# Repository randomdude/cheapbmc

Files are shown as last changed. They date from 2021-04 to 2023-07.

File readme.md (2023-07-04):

= About = 

This is a very simple tool to control a PC's power state. It offers functions to 'press' the power button (controlled via a relay), the 'reset' button, and to observe the current power state of the PC.

It connects to the PC's ATX power-supply header, and uses an ESP8266 to expose a web interface via SSL. The web interface uses mutual SSL (ie, the client authenticates with a certificate and the server authenticates with a certificate).

= Building =

Refer to the Jenkinsfile, or:

```
git clone https://github.com/Microsoft/vcpkg.git
cd vcpkg
bootstrap-vcpkg.bat
vcpkg integrate install
vcpkg install curl[tool] curl[openssl]
```

You'll need to generate keys first - cd to keys/ and run `generate.sh`.

= Use = 

There's no real commandline tool yet (TODO!) but you can test with cURL.

```
# curl --cert access.crt --key access.key --cacert ca.crt https://192.168.90.23 
<html><head></head><a href="doPower">Power button control</a></br><a href="doReset">Reset button control</a></br><a href="getTargetStatus">Get target power LED state</a></br></html>
# curl --cert access.crt --key access.key --cacert ca.crt https://192.168.90.23/getTargetStatus 
OFF
aliz@nuc:/foo# curl -X POST --cert access.crt --key access.key --cacert ca.crt https://192.168.90.23/doPower?thingToDo=short
```

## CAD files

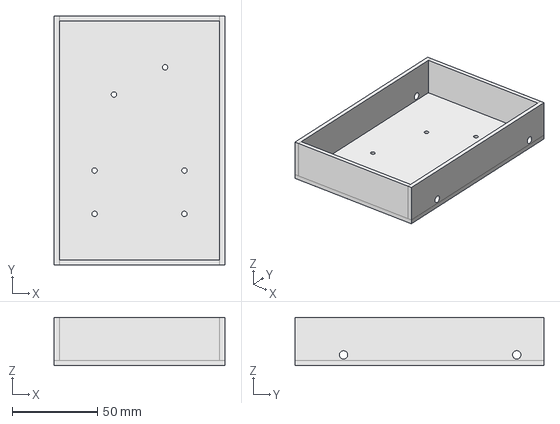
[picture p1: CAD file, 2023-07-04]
enclosure/3_5_inchDiskSized.FCStd
100.2 x 146.1 x 28.4 mm

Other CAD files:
enclosure/globals.FCStd

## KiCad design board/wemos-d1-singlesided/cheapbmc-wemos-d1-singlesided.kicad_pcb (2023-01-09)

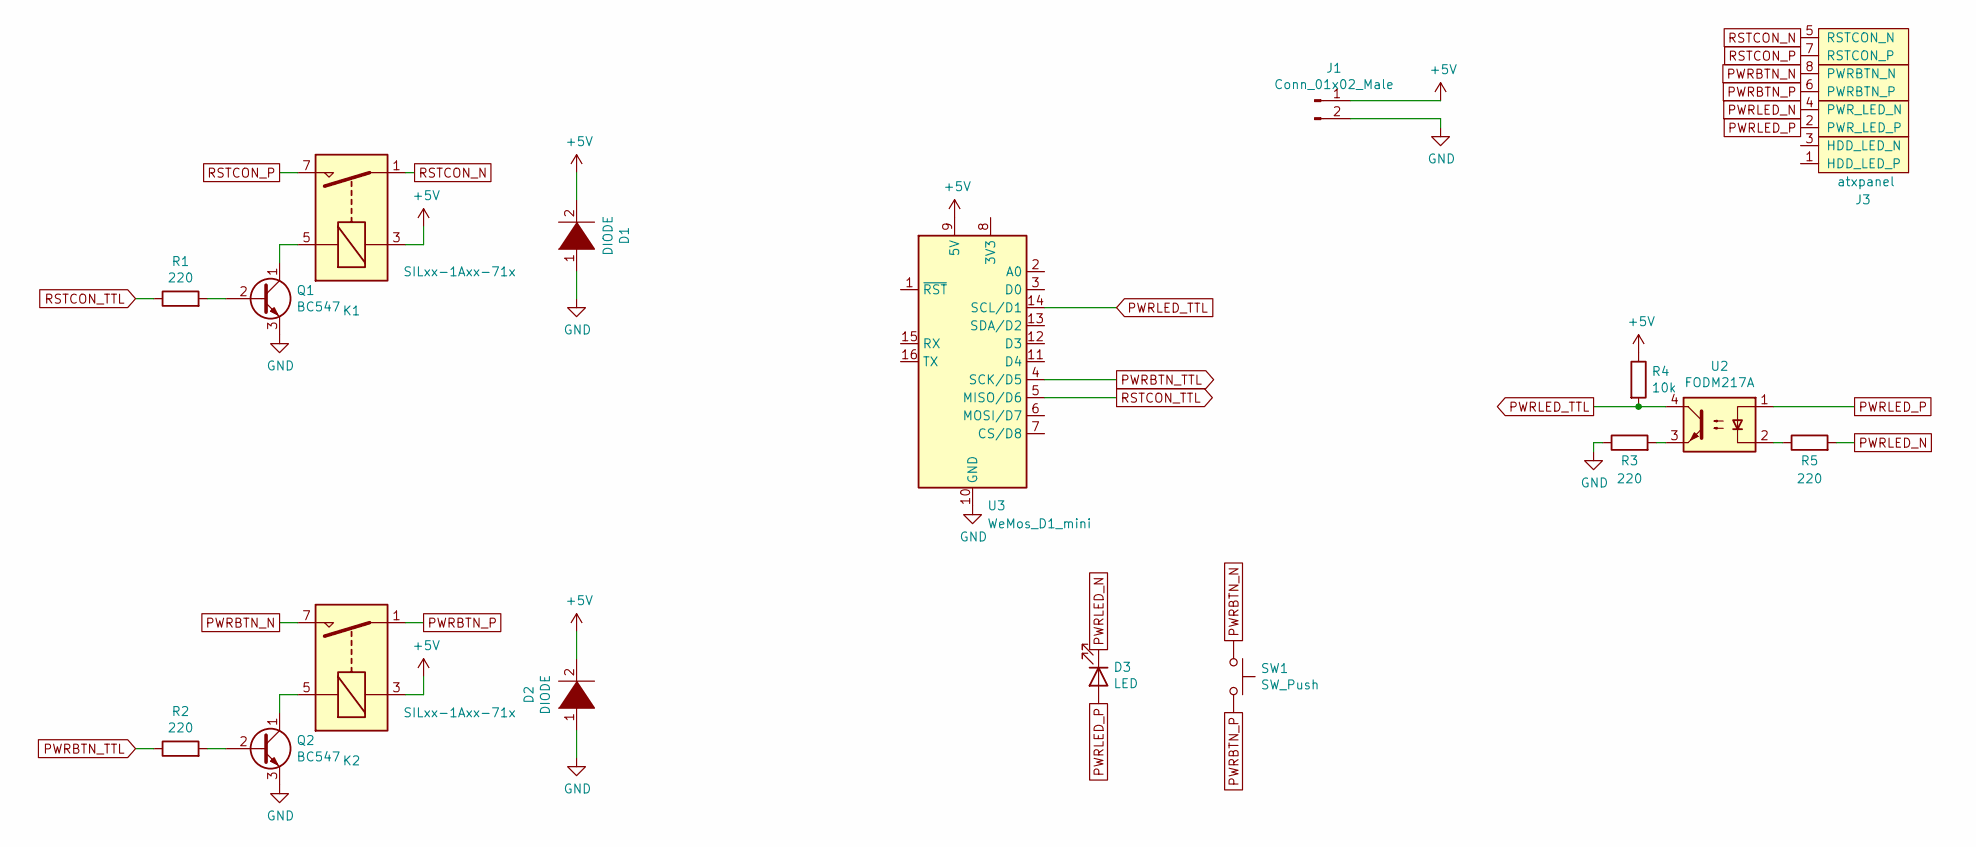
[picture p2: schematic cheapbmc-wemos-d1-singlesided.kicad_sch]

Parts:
D1, D2: DIODE; D_A-405_P7.62mm_Horizontal
D3: LED; LED_D3.0mm
J1: Conn_01x02_Male; PinHeader_1x02_P2.54mm_Vertical
J3: atxpanel; atx-panel-horz-inverted
K1, K2: SILxx-1Axx-71x; Relay_SPST_StandexMeder_SIL_Form1A
Q1, Q2: BC547; TO-92_Inline_Wide
R1, R2, R3, R5: 220; R_Axial_DIN0204_L3.6mm_D1.6mm_P7.62mm_Horizontal
R4: 10k; R_Axial_DIN0204_L3.6mm_D1.6mm_P7.62mm_Horizontal
SW1: SW_Push; SW_Tactile_SKHH_Angled
U2: FODM217A; DIP-4_W7.62mm
U3: WeMos_D1_mini; WEMOS_D1_mini_light

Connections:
+5V: D1.2 (A), D2.2 (A), J1.1, K1.3, K2.3, R4.1, U3.9 (5V)
GND: D1.1 (K), D2.1 (K), J1.2, Q1.3 (E), Q2.3 (E), R3.1, U3.10 (GND)
unnamed: K1.5, Q1.1 (C)
unnamed: K2.5, Q2.1 (C)
unnamed: Q1.2 (B), R1.2
unnamed: Q2.2 (B), R2.2
unnamed: R3.2, U2.3
unnamed: R5.1, U2.2
PWRBTN_N: J3.8 (PWRBTN_N), K2.7, SW1.1
PWRBTN_P: J3.6 (PWRBTN_P), K2.1, SW1.2
PWRBTN_TTL: R2.1, U3.4 (SCK/D5)
PWRLED_N: D3.1 (K), J3.4 (PWR_LED_N), R5.2
PWRLED_P: D3.2 (A), J3.2 (PWR_LED_P), U2.1
PWRLED_TTL: R4.2, U2.4, U3.14 (SCL/D1)
RSTCON_N: J3.5 (RSTCON_N), K1.1
RSTCON_P: J3.7 (RSTCON_P), K1.7
RSTCON_TTL: R1.1, U3.5 (MISO/D6)

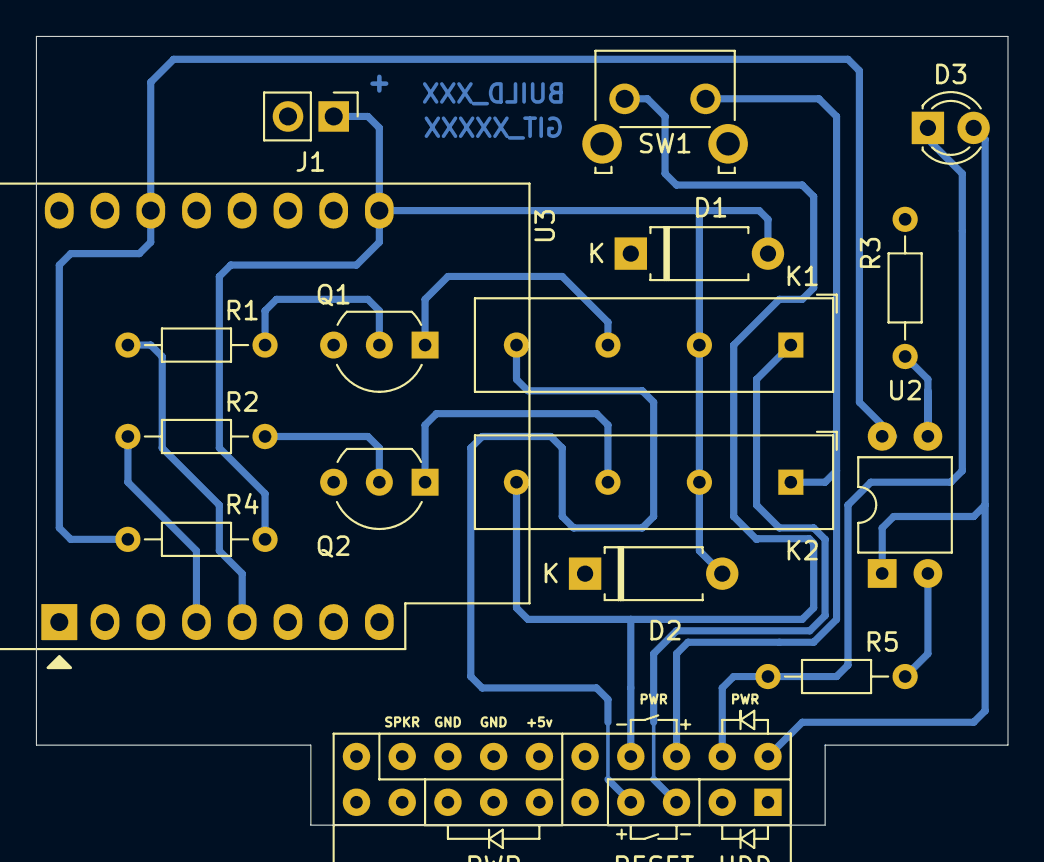
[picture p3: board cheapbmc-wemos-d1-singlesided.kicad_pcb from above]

Board: 2 copper layers, 54.0 x 43.8 mm, 17 parts (0 on the bottom side), 17 nets.

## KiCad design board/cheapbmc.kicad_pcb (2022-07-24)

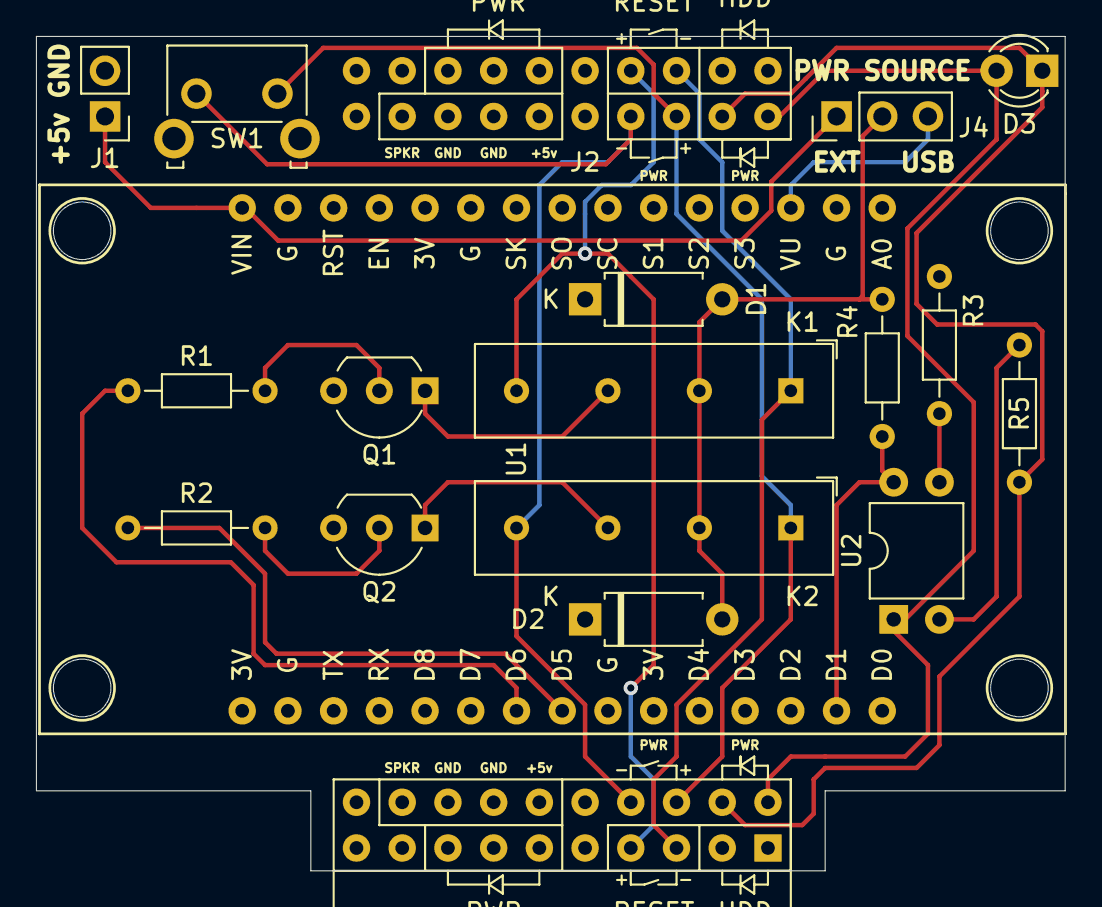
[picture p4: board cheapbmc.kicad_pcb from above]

Board: 2 copper layers, 57.2 x 46.4 mm, 23 parts (0 on the bottom side), 19 nets.

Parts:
D1, D2: DIODE; D_A-405_P7.62mm_Horizontal
D3: LED; LED_D3.0mm
H1, H2, H3, H4: MountingHole; MountingHole_3.2mm_M3
J1: Conn_01x02_Male; PinHeader_1x02_P2.54mm_Vertical
J2: atxpanel; atx-panel
J3: atxpanel; atx-panel-horz-inverted
J4: Conn_01x03_Male; PinHeader_1x03_P2.54mm_Vertical
K1, K2: SILxx-1Axx-71x; Relay_SPST_StandexMeder_SIL_Form1A
Q1, Q2: BC547; TO-92_Inline_Wide
R1, R2, R3, R5: 220; R_Axial_DIN0204_L3.6mm_D1.6mm_P7.62mm_Horizontal
R4: 10k; R_Axial_DIN0204_L3.6mm_D1.6mm_P7.62mm_Horizontal
SW1: SW_Push; SW_Tactile_SKHH_Angled
U1: NodeMCU1.0(ESP-12E); NodeMCU-LoLinV3
U2: FODM217A; DIP-4_W7.62mm

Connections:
+5V: D1.2 (A), D2.2 (A), J4.2, K1.3, K2.3, R4.1
GND: D1.1 (K), D2.1 (K), J1.2, Q1.3 (E), Q2.3 (E), R3.1, U1.10 (GND)
unnamed: J1.1, J4.1, U1.15 (VIN)
unnamed: J4.3, U1.3 (RSV)
unnamed: K1.5, Q1.1 (C)
unnamed: K2.5, Q2.1 (C)
unnamed: Q1.2 (B), R1.2
unnamed: Q2.2 (B), R2.2
unnamed: R3.2, U2.3
unnamed: R5.1, U2.2
PWRBTN_N: J2.8 (PWRBTN_N), J3.8 (PWRBTN_N), K2.7, SW1.1
PWRBTN_P: J2.6 (PWRBTN_P), J3.6 (PWRBTN_P), K2.1, SW1.2
PWRBTN_TTL: R2.1, U1.23 (D5(GPIO14))
PWRLED_N: D3.1 (K), J2.4 (PWR_LED_N), J3.4 (PWR_LED_N), R5.2
PWRLED_P: D3.2 (A), J2.2 (PWR_LED_P), J3.2 (PWR_LED_P), U2.1
PWRLED_TTL: R4.2, U1.29 (D1(GPIO5)), U2.4
RSTCON_N: J2.5 (RSTCON_N), J3.5 (RSTCON_N), K1.1
RSTCON_P: J2.7 (RSTCON_P), J3.7 (RSTCON_P), K1.7
RSTCON_TTL: R1.1, U1.22 (D6(GPIO12))

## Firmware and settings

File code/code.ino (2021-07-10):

#include <ESP8266WiFi.h>
#include <ESP8266WebServerSecure.h>
#include <time.h>

#include <WiFiUdp.h>

#include "app.h"


void setup()
{
	ESP.wdtDisable();
	*((volatile uint32_t*)0x60000900) &= ~(1); // Hardware WDT OFF
}

void loop()
{
	app theapp;

	ESP.wdtDisable();
	*((volatile uint32_t*)0x60000900) &= ~(1); // Hardware WDT OFF
	theapp.idleForever();
}

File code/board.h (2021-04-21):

#define LED_BUILTIN 2
#define PIN_POWERBUTTON 14
#define PIN_RESETBUTTON 12
#define PIN_POWERSENSOR 5

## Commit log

2021-04-21 Add some mounting holes
    [cheapbmc.kicad_pcb, cheapbmc.sch]
2021-04-21 move R4 out of H4's courtyard
    [cheapbmc.kicad_pcb]
2021-04-21 Rotate around input panel connector
2021-04-21 Improve front-panel footprint, add git/build silk
    [cheapbmc.kicad_pcb, cheapbmc.sch]
2021-04-21 Move board into /board directory
    [cheapbmc.kicad_pcb, cheapbmc.sch]
2021-04-21 Correct path to kicad project
2021-05-14 Enlarge transistor footprints, correct relay footprint, add power selector switch, power LED/buttons
    [cheapbmc.kicad_pcb, cheapbmc.sch]
2021-05-14 run file recovery
    [cheapbmc.sch]
2021-05-16 Move connector away from mounting hole
    [cheapbmc.kicad_pcb]
2021-05-16 adjust gnd/5v silk
    [cheapbmc.kicad_pcb]
2021-05-16 remove text from mounting holes
    [cheapbmc.kicad_pcb]
2021-08-27 Package into nuget package; support power button presses from .net
2021-10-06 check board in parallel with build
2021-10-06 add missing close-bracket
2022-02-03 board: Add current-limiting resistor on power status optoisolator
    [cheapbmc.kicad_pcb, cheapbmc.sch]
2022-04-16 Move to kicad 6
    [cheapbmc.kicad_pcb]
2022-04-16 Add kicad6 project files
    [cheapbmc.kicad_sch]
2022-07-24 fix DRC, tidy up a bit
    [cheapbmc.kicad_pcb]
2022-12-16 add wemos-d1 board
    [cheapbmc-wemos-d1-singlesided.kicad_pcb, cheapbmc-wemos-d1-singlesided.kicad_sch, cheapbmc.sch]
2023-01-05 Fix operation when power button is PWM'ed
2023-01-09 wemos: avoid 0.8mm drill because of broken 0.8mm drill bit
    [cheapbmc-wemos-d1-singlesided.kicad_pcb, cheapbmc-wemos-d1-singlesided.kicad_sch]
2023-07-04 Add 3.5-inch-disk-sized enclosure
    [3_5_inchDiskSized.FCStd, globals.FCStd]
2023-07-04 ensure we check out main project before trying to build enclosure
